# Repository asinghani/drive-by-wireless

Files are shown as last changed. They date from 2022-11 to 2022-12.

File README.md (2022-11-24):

# Distributed Embedded Final Project

UWB drive-by-wireless

## Build Instructions

1. Clone pico-sdk and pico-extras and put them in your environment variables as `PICO_SDK_PATH` and `PICO_EXTRAS_PATH`. Also clone FreeRTOS-Kernel, `smp` branch and put its path as `FREERTOS_KERNEL_PATH`

2. `cd firmware`

3. `rm -r build; mkdir build; cd build` (its safest to delete and re-make the build directory every time because CMake caches things incorrectly sometimes)

4. `cmake .. && make -j8` (this will build all 3 targets - cockpit, steering, and drivetrain)

5. This should yield `zone_cockpit.uf2`, `zone_steering.uf2`, and `zone_drivetrain.uf2` which can be flashed to the boards.

## File Structure

```
- firmware/ (the directory for the firmware)
    - main.c (main entry point, shouldn't put any more code into this file)
    - utils.h (utility functions for math, safety, etc.)
    - config.h (configuration of GPIO pins, etc.)
    - FreeRTOSConfig.h
    - z_cockpit/
        - main_cockpit.c (entry point for cockpit zone)
    - z_drivetrain/
        - main_drivetrain.c (entry point for drivetrain zone)
    - z_steering/
        - main_steering.c (entry point for steering zone)
    - common/ (common stuff)
        - freertos_callbacks.c
    - peripherals/ (drivers for hardware peripherals)
        - testpoints.h (driver for test points)

- experimental/ (for test programs)

- scripts/ (scripts to run on a host machine)
    - proxy_gui.py (the steering wheel proxy, to run on Windows)

- hardware/ (hardware / CAD files)
    - 449pcb_v1/ (PCB CAD)
    - schematic.pdf (board schematic, for easy reference)

```

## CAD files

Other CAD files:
hardware/top_plate.dwg

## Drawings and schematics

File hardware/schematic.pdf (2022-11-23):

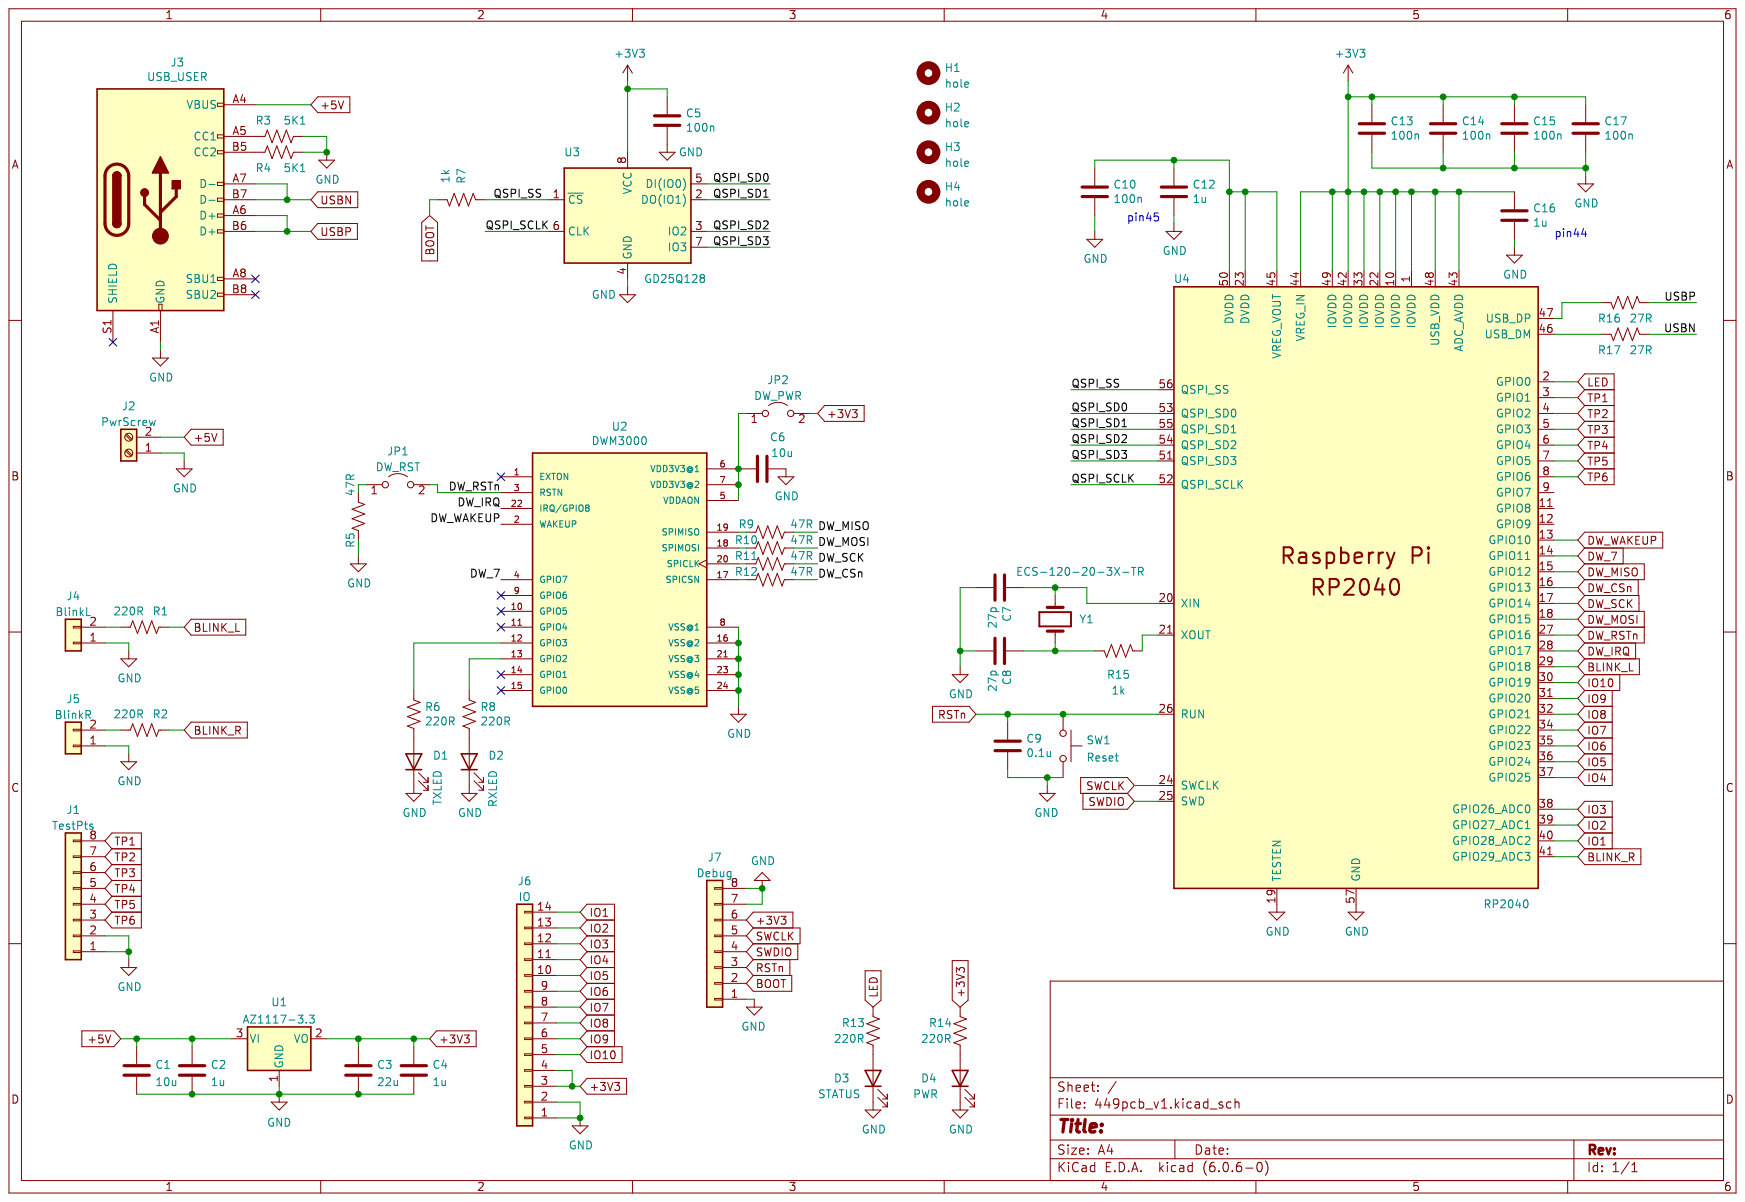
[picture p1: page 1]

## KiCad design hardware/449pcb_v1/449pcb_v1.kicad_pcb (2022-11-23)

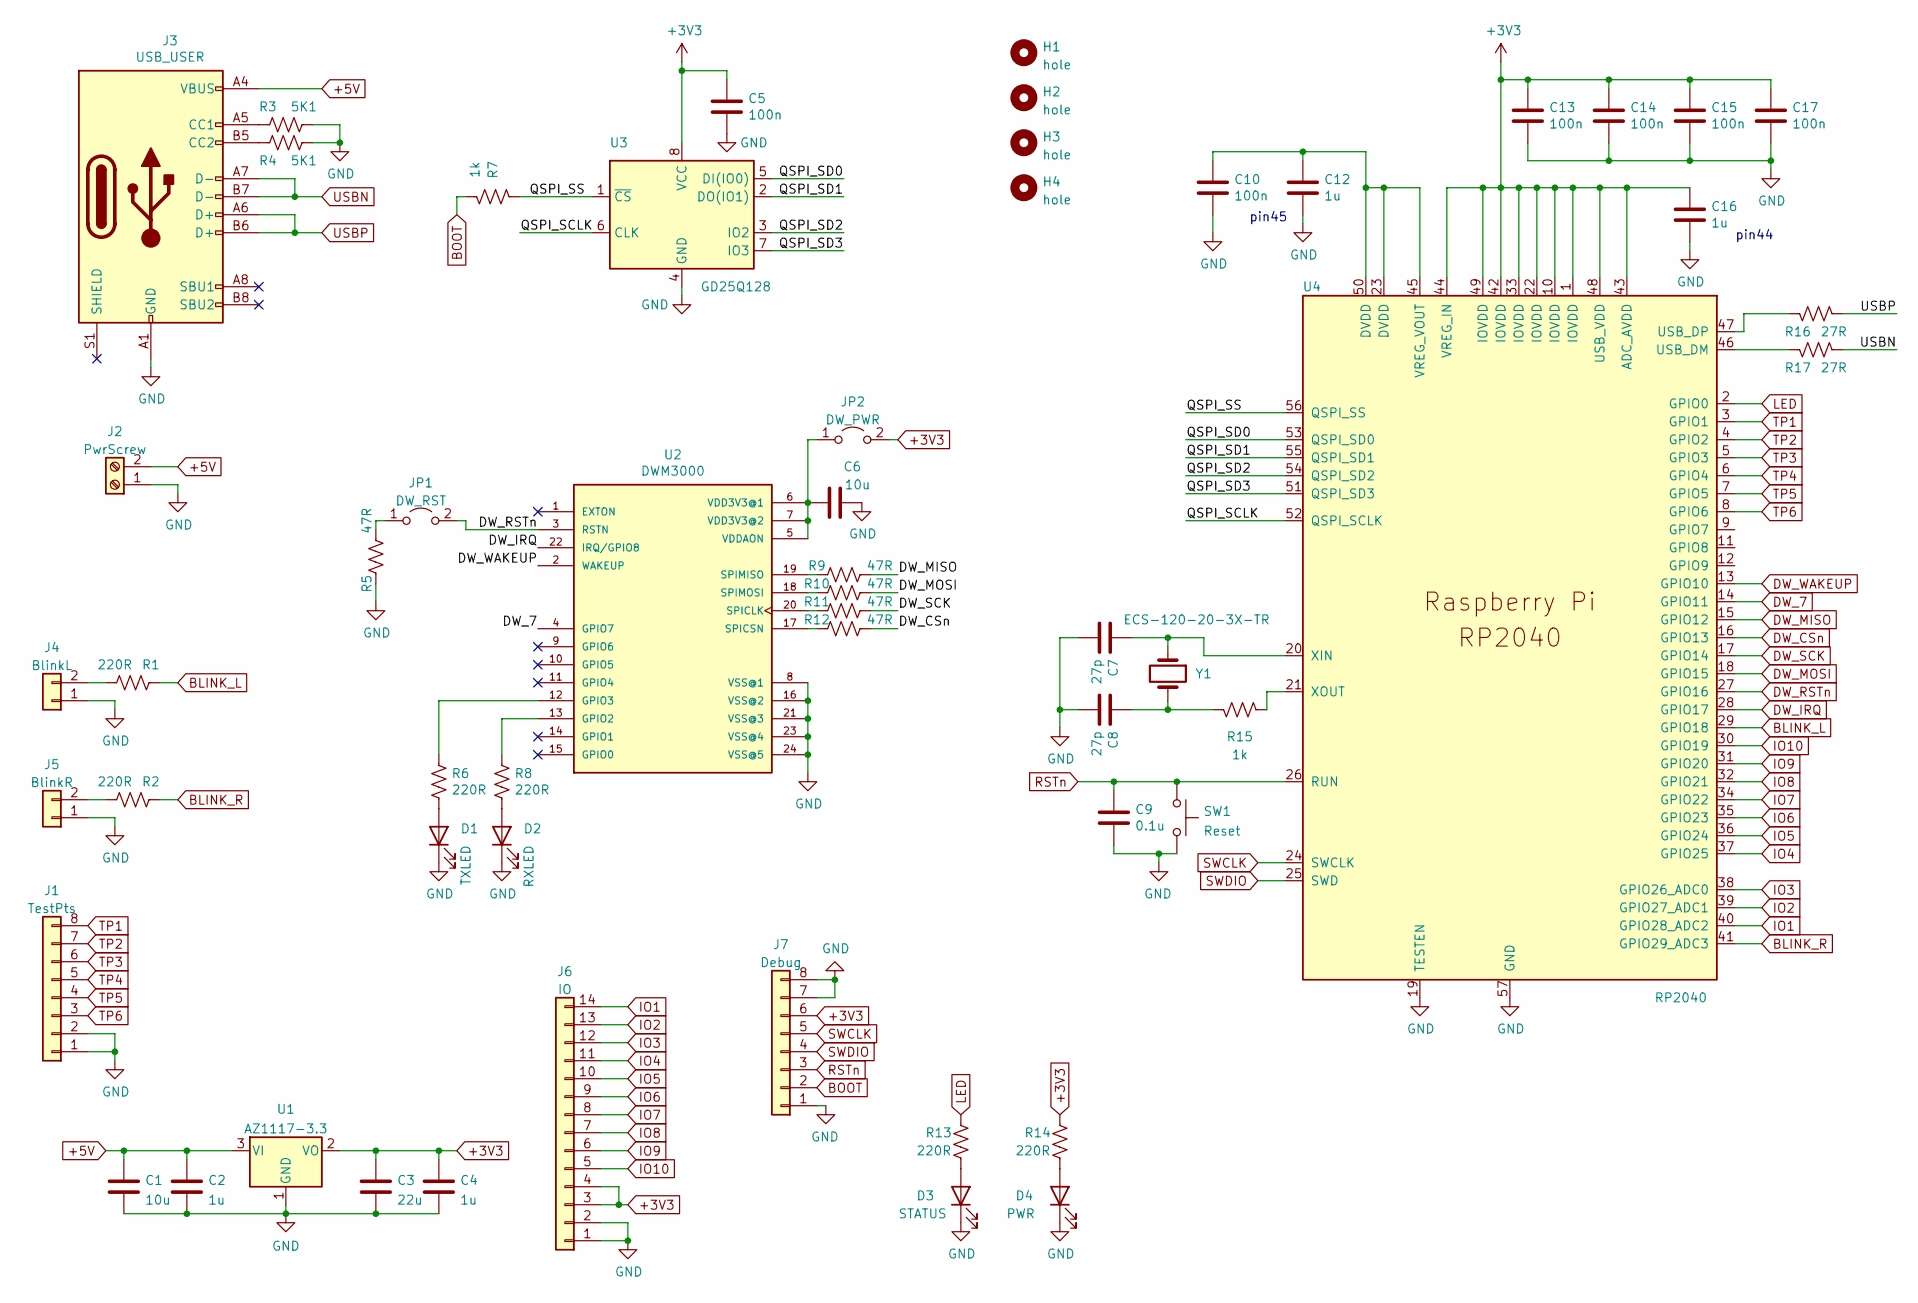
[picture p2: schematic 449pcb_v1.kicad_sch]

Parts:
C1, C6: 10u; C_0603_1608Metric
C2, C4, C12, C16: 1u; C_0603_1608Metric
C3: 22u; C_0603_1608Metric
C5, C10, C13, C14, C15, C17: 100n; C_0603_1608Metric
C7, C8: 27p; C_0603_1608Metric
C9: 0.1u; C_0603_1608Metric
D1: TXLED; LED_0805_2012Metric
D2: RXLED; LED_0805_2012Metric
D3: STATUS; LED_0805_2012Metric
D4: PWR; LED_0805_2012Metric
H1, H2, H3, H4: hole; MountingHole_3.2mm_M3_Pad_Via
J1: TestPts; PinHeader_1x08_P2.54mm_Vertical
J2: PwrScrew; TerminalBlock_4Ucon_1x02_P3.50mm_Horizontal
J3: USB_USER; USB_C_HRO-31-M-12_nofront
J4: BlinkL; PinHeader_1x02_P2.54mm_Vertical
J5: BlinkR; PinHeader_1x02_P2.54mm_Vertical
J6: IO; PinHeader_1x14_P2.54mm_Vertical
J7: Debug; PinHeader_1x08_P2.54mm_Vertical
JP1: DW_RST; PinHeader_1x02_P2.54mm_Vertical
JP2: DW_PWR; PinHeader_1x02_P2.54mm_Vertical
R1, R2, R6, R8, R13, R14: 220R; R_0603_1608Metric
R3, R4: 5K1; R_0603_1608Metric
R5, R9, R10, R11, R12: 47R; R_0603_1608Metric
R7, R15: 1k; R_0603_1608Metric
R16, R17: 27R; R_0603_1608Metric
SW1: Reset; SW_SPST_PTS810
U1: AZ1117-3.3; SOT-223-3_TabPin2
U2: DWM3000
U3: GD25Q128; SOIC-8_5.23x5.23mm_P1.27mm
U4: RP2040; RP2040-QFN-56
Y1: ECS-120-20-3X-TR; XTAL_ECS-120-20-3X-TR

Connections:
+3V3: C3.1, C4.1, C5.1, C13.1, C14.1, C15.1, C16.1, C17.1, J6.3, J6.4, J7.6, JP2.2 (B), R14.1, U1.2 (VO), U3.8 (VCC), U4.1 (IOVDD), U4.10 (IOVDD), U4.22 (IOVDD), U4.33 (IOVDD), U4.42 (IOVDD), U4.43 (ADC_AVDD), U4.44 (VREG_IN), U4.48 (USB_VDD), U4.49 (IOVDD)
+5V: C1.1, C2.1, J2.2, J3.A4 (VBUS), J3.A9 (VBUS), J3.B4 (VBUS), J3.B9 (VBUS), U1.3 (VI)
/QSPI_SCLK: U3.6 (CLK), U4.52 (QSPI_SCLK)
/QSPI_SD0: U3.5 (DI(IO0)), U4.53 (QSPI_SD0)
/QSPI_SD1: U3.2 (DO(IO1)), U4.55 (QSPI_SD1)
/QSPI_SD2: U3.3 (IO2), U4.54 (QSPI_SD2)
/QSPI_SD3: U3.7 (IO3), U4.51 (QSPI_SD3)
/QSPI_SS: R7.2, U3.1 (~CS), U4.56 (QSPI_SS)
BLINK_L: R1.1, U4.29 (GPIO18)
BLINK_R: R2.1, U4.41 (GPIO29_ADC3)
BOOT: J7.2, R7.1
DW_7: U2.4 (GPIO7), U4.14 (GPIO11)
DW_CSn: R12.1, U4.16 (GPIO13)
DW_IRQ: U2.22 (IRQ/GPIO8), U4.28 (GPIO17)
DW_MISO: R9.1, U4.15 (GPIO12)
DW_MOSI: R10.1, U4.18 (GPIO15)
DW_RSTn: JP1.2 (B), U2.3 (RSTN), U4.27 (GPIO16)
DW_SCK: R11.1, U4.17 (GPIO14)
DW_WAKEUP: U2.2 (WAKEUP), U4.13 (GPIO10)
GND: C1.2, C2.2, C3.2, C4.2, C5.2, C6.1, C7.2, C8.2, C9.2, C10.2, C12.2, C13.2, C14.2, C15.2, C16.2, C17.2, D1.1 (K), D2.1 (K), D3.1 (K), D4.1 (K), J1.1, J1.2, J2.1, J3.A1 (GND), J3.A12 (GND), J3.B1 (GND), J3.B12 (GND), J4.1, J5.1, J6.1, J6.2, J7.1, J7.7, J7.8, R3.2, R4.2, R5.2, SW1.2, U1.1 (GND), U2.8 (VSS@1), U2.16 (VSS@2), U2.21 (VSS@3), U2.23 (VSS@4), U2.24 (VSS@5), U3.4 (GND), U4.19 (TESTEN), U4.57 (GND)
IO1: J6.14, U4.40 (GPIO28_ADC2)
IO2: J6.13, U4.39 (GPIO27_ADC1)
IO3: J6.12, U4.38 (GPIO26_ADC0)
IO4: J6.11, U4.37 (GPIO25)
IO5: J6.10, U4.36 (GPIO24)
IO6: J6.9, U4.35 (GPIO23)
IO7: J6.8, U4.34 (GPIO22)
IO8: J6.7, U4.32 (GPIO21)
IO9: J6.6, U4.31 (GPIO20)
IO10: J6.5, U4.30 (GPIO19)
LED: R13.1, U4.2 (GPIO0)
unnamed: C6.2, JP2.1 (A), U2.5 (VDDAON), U2.6 (VDD3V3@1), U2.7 (VDD3V3@2)
unnamed: C7.1, U4.20 (XIN), Y1.1
unnamed: C8.1, R15.2, Y1.2
unnamed: C10.1, C12.1, U4.23 (DVDD), U4.45 (VREG_VOUT), U4.50 (DVDD)
unnamed: D1.2 (A), R6.2
unnamed: D2.2 (A), R8.2
unnamed: J3.A5 (CC1), R3.1
unnamed: J3.B5 (CC2), R4.1
unnamed: J4.2, R1.2
unnamed: J5.2, R2.2
unnamed: JP1.1 (A), R5.1
unnamed: R6.1, U2.12 (GPIO3)
unnamed: R8.1, U2.13 (GPIO2)
unnamed: R9.2, U2.19 (SPIMISO)
unnamed: R10.2, U2.18 (SPIMOSI)
unnamed: R11.2, U2.20 (SPICLK)
unnamed: R12.2, U2.17 (SPICSN)
unnamed: D3.2 (A), R13.2
unnamed: D4.2 (A), R14.2
unnamed: R15.1, U4.21 (XOUT)
unnamed: R17.2, U4.46 (USB_DM)
unnamed: R16.2, U4.47 (USB_DP)
RSTn: C9.1, J7.3, SW1.1, U4.26 (RUN)
SWCLK: J7.5, U4.24 (SWCLK)
SWDIO: J7.4, U4.25 (SWD)
TP1: J1.8, U4.3 (GPIO1)
TP2: J1.7, U4.4 (GPIO2)
TP3: J1.6, U4.5 (GPIO3)
TP4: J1.5, U4.6 (GPIO4)
TP5: J1.4, U4.7 (GPIO5)
TP6: J1.3, U4.8 (GPIO6)
USBN: J3.A7 (D-), J3.B7 (D-), R17.1
USBP: J3.A6 (D+), J3.B6 (D+), R16.1

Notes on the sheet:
pin44
pin45

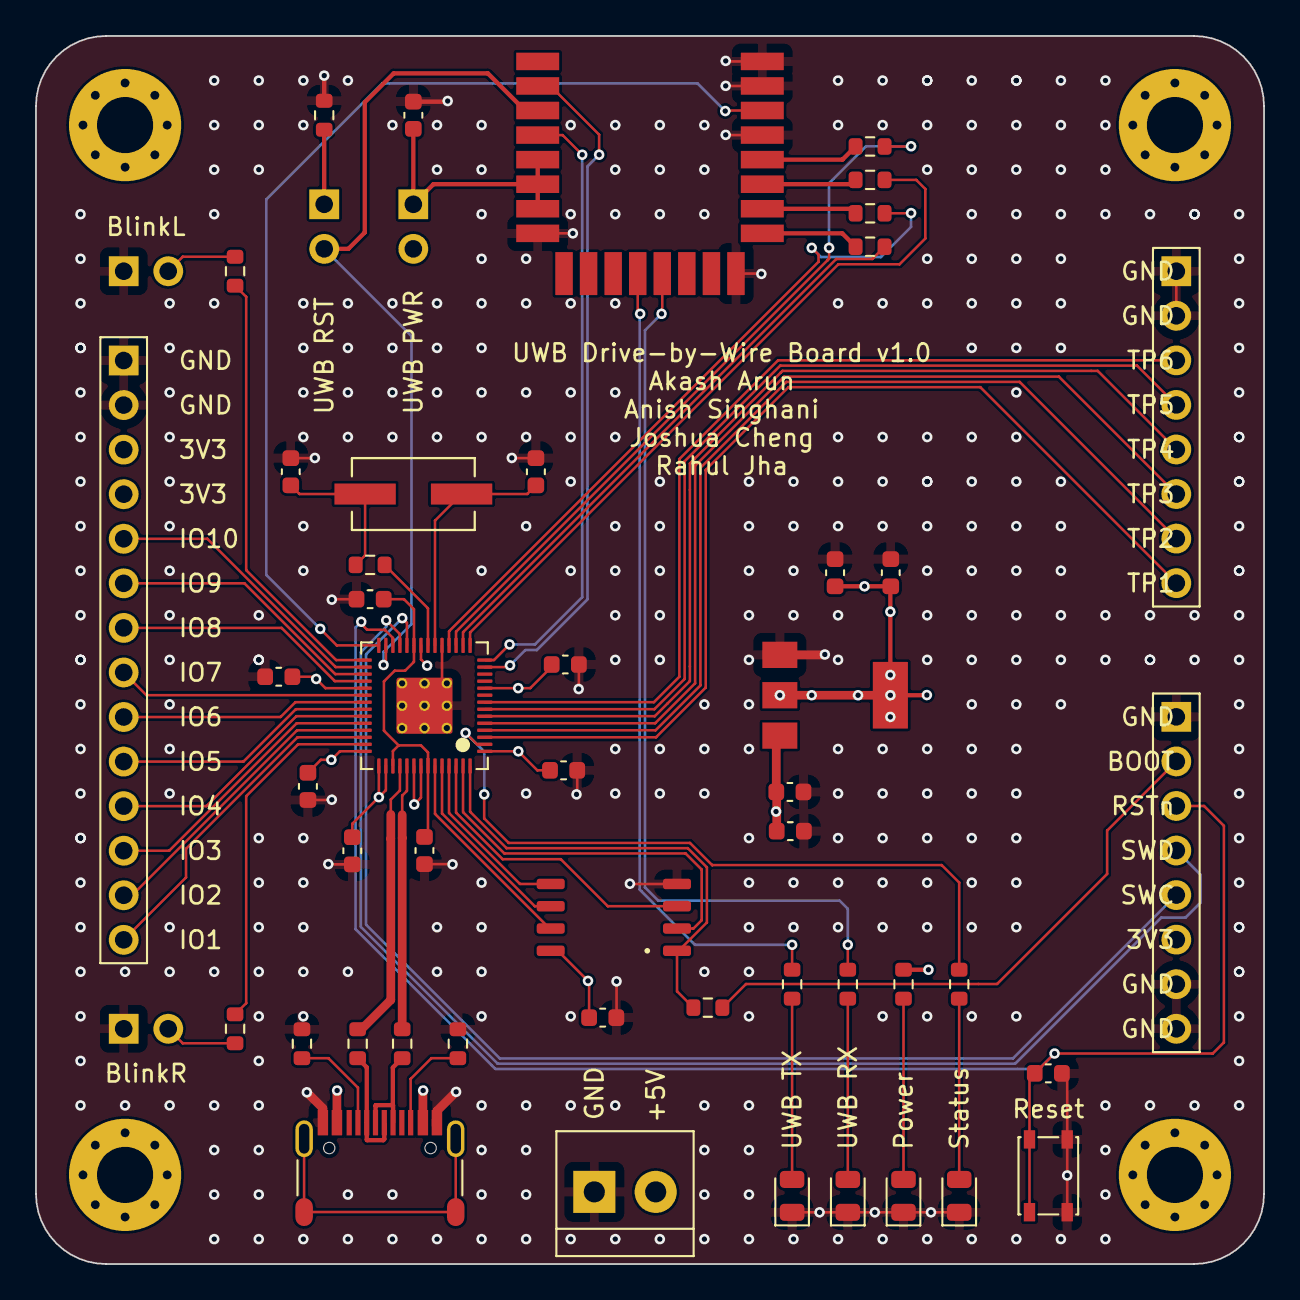
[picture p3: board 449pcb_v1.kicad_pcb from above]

Board: 4 copper layers, 70.0 x 70.0 mm, 56 parts (0 on the bottom side), 64 nets.

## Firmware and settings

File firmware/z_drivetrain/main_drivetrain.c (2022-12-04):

#include "FreeRTOS.h"
#include "task.h"
#include "semphr.h"

#include <stdio.h>
#include <string.h>
#include "peripherals/testpoints.h"
#include "peripherals/blinkers.h"
#include "peripherals/drive_motor.h"
#include "peripherals/voltage_monitor.h"

#include "pico/stdlib.h"
#include "pico/stdio.h"
#include "hardware/adc.h"
#include "hardware/uart.h"
#include "hardware/watchdog.h"
#include "config.h"

#include "crypto/crypto.h"
#include "decawave/uwb_config.h"
#include "decawave/uwb_library.h"
#include "config.h"
#include "utils.h"
#include "types.h"

struct DrivetrainState {
    uint8_t throttle;
    bool brake;
    float voltage_vbat;
    float voltage_vreg;

    // ts_offset = (our clock) - (base clock)
    int32_t ts_offset;
    int32_t blinker_basis_ts;
    bool blink_left;
    bool blink_right;

    bool is_failure_state;
} shm_drivetrain;

// Hardware setup
void drivetrain_setup() {
    memset(&shm_drivetrain, 0, sizeof(shm_drivetrain));

    uwb_init();
    blinkers_init();
    drive_motor_init();
    voltage_monitor_init();

    // Setup LED strip
    uart_init(DRIVETRAIN_LED_STRIP_UART, 115200);
    gpio_set_function(DRIVETRAIN_LED_STRIP_TX, GPIO_FUNC_UART);
}

static void drivetrain_uwb_task(void *arg);
static void drivetrain_motor_task(void *arg);
static void drivetrain_vmon_task(void *arg);
static void drivetrain_led_strip_task(void *arg);

void drivetrain_main() {
    printf("Start drivetrain_main\n");
    drivetrain_setup();

    TaskHandle_t uwb_task;
    xTaskCreate(drivetrain_uwb_task, "drivetrain_uwb_task",
            configMINIMAL_STACK_SIZE, NULL, tskIDLE_PRIORITY + 3, &uwb_task);
    vTaskCoreAffinitySet(uwb_task, 2);

    TaskHandle_t motor_task;
    xTaskCreate(drivetrain_motor_task, "drivetrain_motor_task",
            configMINIMAL_STACK_SIZE, NULL, tskIDLE_PRIORITY + 2, &motor_task);
    vTaskCoreAffinitySet(motor_task, 1);

    TaskHandle_t vmon_task;
    xTaskCreate(drivetrain_vmon_task, "drivetrain_vmon_task",
            configMINIMAL_STACK_SIZE, NULL, tskIDLE_PRIORITY + 4, &vmon_task);
    vTaskCoreAffinitySet(vmon_task, 1);

    TaskHandle_t led_strip_task;
    xTaskCreate(drivetrain_led_strip_task, "drivetrain_led_strip_task",
            configMINIMAL_STACK_SIZE, NULL, tskIDLE_PRIORITY + 5, &led_strip_task);
    vTaskCoreAffinitySet(led_strip_task, 1);

    printf("Starting scheduler\n");
    vTaskStartScheduler();
}

void _drivetrain_uwb_task_idle() {
    blinkers_update(shm_drivetrain.ts_offset, shm_drivetrain.blinker_basis_ts, shm_drivetrain.blink_left,
                        shm_drivetrain.blink_right, shm_drivetrain.is_failure_state);
}

static uint8_t tx_pkt_raw[120];
static uint8_t tx_pkt_enc[120];
static uint8_t rx_pkt_enc[128];
static uint8_t rx_pkt_raw[128];

static void drivetrain_uwb_task(void *arg) {
	TickType_t tick = xTaskGetTickCount();

    int ctr = 0;
    bool success;
    int32_t last_rx_ts = 0;

    // Use fixed-size buffers to facilitate encryption,
    // but alias them to structs to make manipulation easier
    drivetrain_pkt_t *tx_pkt = (void*) &tx_pkt_raw;
    cockpit_pkt_t *rx_pkt = (void*) &rx_pkt_raw;

    while (true) {
        memset(rx_pkt_raw, 0, sizeof(rx_pkt_enc));
        success = (receive_msg(rx_pkt_enc, _drivetrain_uwb_task_idle) != -1);
        success = success && crypto_decrypt(rx_pkt_enc, rx_pkt_raw);
        if (success && (rx_pkt->src == ZID_COCKPIT) && 
                (rx_pkt->dst == ZONE_ID)) {

            tp_raise(ZD_TP_UWB_RX);

            last_rx_ts = millis();
            shm_drivetrain.throttle = rx_pkt->throttle;
            shm_drivetrain.brake = rx_pkt->brake;
            shm_drivetrain.ts_offset = last_rx_ts - rx_pkt->current_ts;
            shm_drivetrain.blinker_basis_ts = rx_pkt->blinker_basis_ts;
            shm_drivetrain.blink_left = rx_pkt->blink_left;
            shm_drivetrain.blink_right = rx_pkt->blink_right;
            shm_drivetrain.is_failure_state = rx_pkt->is_failure_state;

            tx_pkt->src = ZONE_ID;
            tx_pkt->dst = ZID_COCKPIT;
            tx_pkt->voltage_vbat = shm_drivetrain.voltage_vbat;
            tx_pkt->voltage_vreg = shm_drivetrain.voltage_vreg;
            crypto_encrypt(tx_pkt_raw, tx_pkt_enc);
            tp_raise(ZD_TP_UWB_TX);
            send_msg(sizeof(tx_pkt_enc), tx_pkt_enc, 0, _drivetrain_uwb_task_idle);
        }

        if ((millis() - last_rx_ts) > COMM_TIMEOUT_MS) {
            shm_drivetrain.is_failure_state = true;
            shm_drivetrain.throttle = 0;
            shm_drivetrain.brake = true;
        }

        _drivetrain_uwb_task_idle();
        watchdog_update();
        tp_statusled(shm_drivetrain.is_failure_state);
        ctr++;
    }
}

static void drivetrain_motor_task(void *arg) {
	TickType_t tick = xTaskGetTickCount();

    while (true) {
		vTaskDelayUntil(&tick, 5);
        bool is_brake = (shm_drivetrain.is_failure_state ? 1 : shm_drivetrain.brake);
        drive_motor_set(shm_drivetrain.is_failure_state ? 0 : shm_drivetrain.throttle, is_brake);
        tp_raise(ZD_TP_MOTOR_SET);
        tp_set(ZD_TP_IS_BRAKE, is_brake);
    }
}

static void drivetrain_vmon_task(void *arg) {
	TickType_t tick = xTaskGetTickCount();

    while (true) {
		vTaskDelayUntil(&tick, 200);
        shm_drivetrain.voltage_vbat = voltage_monitor_get_vbat();
        shm_drivetrain.voltage_vreg = voltage_monitor_get_5v();
    }
}

static void drivetrain_led_strip_task(void *arg) {
	TickType_t tick = xTaskGetTickCount();

    while (true) {
		vTaskDelayUntil(&tick, 200);
        uint8_t dat = shm_drivetrain.throttle;
        if (shm_drivetrain.is_failure_state) dat = 0;
        if (shm_drivetrain.brake) dat = 0;

        uart_putc_raw(DRIVETRAIN_LED_STRIP_UART, dat);
    }
}

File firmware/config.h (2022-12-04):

#ifndef CONFIG_H
#define CONFIG_H

#define IO_1 28
#define IO_2 27
#define IO_3 26
#define IO_4 25
#define IO_5 24
#define IO_6 23
#define IO_7 22
#define IO_8 21
#define IO_9 20
#define IO_10 19

// Maximum packet loss before failure state
#define MAX_COMM_FAILURES 5
#define COMM_TIMEOUT_MS 80

// Blinker rates
#define ERROR_BLINKER_RATE_MS 150
#define BLINKER_RATE_MS 500

// Blinker control config
#define STEER_THRESH1 30
#define STEER_THRESH2 60

// Cockpit zone config
#define STEERING_UART uart1
#define STEERING_RX IO_8
#define STEERING_TX IO_9

// Steering zone config
#define STEERING_SERVO_IO IO_10
#define STEERING_SERVO_CENTER 1385 // Determined experimentally
#define STEERING_SERVO_RANGE 300
#define STEERING_FEEDBACK_IO IO_1
#define STEERING_FEEDBACK_ADC 2 // ch2 = gpio28

// Drivetrain zone config
#define DRIVETRAIN_EN  IO_8
#define DRIVETRAIN_IN1 IO_9
#define DRIVETRAIN_IN2 IO_10
#define VMON_VBAT IO_1
#define VMON_VBAT_ADC 2 // ch2 = gpio28
#define VMON_5V   IO_2
#define VMON_5V_ADC   1 // ch1 = gpio27

#define DRIVETRAIN_LED_STRIP_UART uart1
#define DRIVETRAIN_LED_STRIP_TX IO_5

// Calibrated emperically
#define VMON_VBAT_SCALE 0.00618871
#define VMON_5V_SCALE 0.00619207

// Blinker I/O pins
#define IO_BLINKL 18
#define IO_BLINKR 29

// UWB I/O pins
#define IO_DW_WAKEUP 10
#define IO_DW_7 11
#define IO_DW_CSn 13
#define IO_DW_RSTn 16
#define IO_DW_IRQ 17

// Test-point I/O pins
#define IO_STATUS 0
#define IO_TP1 1
#define IO_TP2 2
#define IO_TP3 3
#define IO_TP4 4
#define IO_TP5 5
#define IO_TP6 6

// Test point definitions
#define ZC_TP_USB_IN  1
#define ZC_TP_USB_OUT 2
#define ZC_TP_UWB_RX  3
#define ZC_TP_UWB_TX  4

#define ZS_TP_UWB_RX     1
#define ZS_TP_UWB_TX     2
#define ZS_TP_STEER_SET  3
#define ZS_TP_FORCE_READ 4

#define ZD_TP_UWB_RX     1
#define ZD_TP_UWB_TX     2
#define ZD_TP_MOTOR_SET  3
#define ZD_TP_IS_BRAKE   4

#define ZDZS_TP_BLINK_L  5
#define ZDZS_TP_BLINK_R  6

// UWB config
#define UWB_PIN_MISO 12
#define UWB_PIN_CS   13
#define UWB_PIN_SCK  14
#define UWB_PIN_MOSI 15
#define UWB_PIN_RSTN 16
#define UWB_SPI_PORT spi1

// Microseconds to raise test-point for
#define TP_TIME_US 100

#define ZID_COCKPIT 0
#define ZID_STEERING 1
#define ZID_DRIVETRAIN 2

#ifdef ZONE_COCKPIT
#define ZONE_ID ZID_COCKPIT 
#endif

#ifdef ZONE_STEERING
#define ZONE_ID ZID_STEERING
#endif

#ifdef ZONE_DRIVETRAIN
#define ZONE_ID ZID_DRIVETRAIN
#endif

#endif

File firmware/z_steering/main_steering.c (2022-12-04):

#include "FreeRTOS.h"
#include "task.h"
#include "semphr.h"

#include <stdio.h>
#include <string.h>
#include "peripherals/testpoints.h"
#include "peripherals/steering_servo.h"
#include "peripherals/blinkers.h"

#include "pico/stdlib.h"
#include "pico/stdio.h"
#include "hardware/adc.h"
#include "hardware/watchdog.h"
#include "config.h"

#include "crypto/crypto.h"
#include "decawave/uwb_config.h"
#include "decawave/uwb_library.h"
#include "config.h"
#include "utils.h"
#include "types.h"

struct SteeringState {
    int8_t angle;
    int8_t feedback;

    // ts_offset = (our clock) - (base clock)
    int32_t ts_offset;
    int32_t blinker_basis_ts;
    bool blink_left;
    bool blink_right;

    bool is_failure_state;
} shm_steering;

// Hardware setup
void steering_setup() {
    memset(&shm_steering, 0, sizeof(shm_steering));
    steering_servo_init();

    uwb_init();
    blinkers_init();
}

static void steering_uwb_task(void *arg);
static void steering_servo_task(void *arg);
static void steering_feedback_task(void *arg);

void steering_main() {
    printf("Start steering_main\n");
    steering_setup();

    TaskHandle_t uwb_task;
    xTaskCreate(steering_uwb_task, "steering_uwb_task",
            configMINIMAL_STACK_SIZE, NULL, tskIDLE_PRIORITY + 3, &uwb_task);
    vTaskCoreAffinitySet(uwb_task, 2);

    TaskHandle_t servo_task;
    xTaskCreate(steering_servo_task, "steering_servo_task",
            configMINIMAL_STACK_SIZE, NULL, tskIDLE_PRIORITY + 2, &servo_task);
    vTaskCoreAffinitySet(servo_task, 1);

    TaskHandle_t feedback_task;
    xTaskCreate(steering_feedback_task, "steering_feedback_task",
            configMINIMAL_STACK_SIZE, NULL, tskIDLE_PRIORITY + 1, &feedback_task);
    vTaskCoreAffinitySet(feedback_task, 1);

    printf("Starting scheduler\n");
    vTaskStartScheduler();
}

void _steering_uwb_task_idle() {
    blinkers_update(shm_steering.ts_offset, shm_steering.blinker_basis_ts, shm_steering.blink_left,
                        shm_steering.blink_right, shm_steering.is_failure_state);
}

static uint8_t tx_pkt_raw[120];
static uint8_t tx_pkt_enc[120];
static uint8_t rx_pkt_enc[128];
static uint8_t rx_pkt_raw[128];

static void steering_uwb_task(void *arg) {
	TickType_t tick = xTaskGetTickCount();

    int ctr = 0;
    bool success;
    int32_t last_rx_ts = 0;

    // Use fixed-size buffers to facilitate encryption,
    // but alias them to structs to make manipulation easier
    steering_pkt_t *tx_pkt = (void*) &tx_pkt_raw;
    cockpit_pkt_t *rx_pkt = (void*) &rx_pkt_raw;

    while (true) {
        memset(rx_pkt_enc, 0, sizeof(rx_pkt_enc));
        success = (receive_msg(rx_pkt_enc, _steering_uwb_task_idle) != -1);
        success = success && crypto_decrypt(rx_pkt_enc, rx_pkt_raw);
        if (success && (rx_pkt->src == ZID_COCKPIT) && 
                (rx_pkt->dst == ZONE_ID)) {
            tp_raise(ZS_TP_UWB_RX);

            last_rx_ts = millis();
            shm_steering.angle = rx_pkt->angle;
            shm_steering.ts_offset = last_rx_ts - rx_pkt->current_ts;
            shm_steering.blinker_basis_ts = rx_pkt->blinker_basis_ts;
            shm_steering.blink_left = rx_pkt->blink_left;
            shm_steering.blink_right = rx_pkt->blink_right;
            shm_steering.is_failure_state = rx_pkt->is_failure_state;

            tx_pkt->src = ZONE_ID;
            tx_pkt->dst = ZID_COCKPIT;
            tx_pkt->feedback = shm_steering.feedback;

            crypto_encrypt(tx_pkt_raw, tx_pkt_enc);
            tp_raise(ZD_TP_UWB_TX);
            send_msg(sizeof(tx_pkt_enc), tx_pkt_enc, 0, _steering_uwb_task_idle);
        }

        if ((millis() - last_rx_ts) > COMM_TIMEOUT_MS) {
            shm_steering.is_failure_state = true;
            shm_steering.angle = 0;
        }

        _steering_uwb_task_idle();
        watchdog_update();
        tp_statusled(shm_steering.is_failure_state);
        ctr++;
    }
}

static void steering_servo_task(void *arg) {
	TickType_t tick = xTaskGetTickCount();

    while (true) {
		vTaskDelayUntil(&tick, 10);
        steering_servo_set(shm_steering.angle);
        tp_raise(ZS_TP_STEER_SET);
    }
}

static void steering_feedback_task(void *arg) {
	TickType_t tick = xTaskGetTickCount();

    while (true) {
		vTaskDelayUntil(&tick, 10);
        shm_steering.feedback = steering_servo_get_feedback(shm_steering.angle);
        tp_raise(ZS_TP_FORCE_READ);
    }
}

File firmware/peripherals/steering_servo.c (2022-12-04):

#include "FreeRTOS.h"
#include "task.h"
#include "semphr.h"

#include <stdint.h>
#include "pico/stdlib.h"
#include "hardware/adc.h"
#include "hardware/pwm.h"
#include "hardware/clocks.h"

#include "config.h"
#include "utils.h"
#include "steering_servo.h"

float servo_clock_div = 0;
float servo_wrap = 0;

void steering_servo_init() {
    // Set up the servo GPIO and PWM peripheral
    gpio_set_function(STEERING_SERVO_IO, GPIO_FUNC_PWM);
    int slice_num = pwm_gpio_to_slice_num(STEERING_SERVO_IO);
    pwm_config config = pwm_get_default_config();
    uint64_t clock_speed = clock_get_hz(clk_sys);
    servo_clock_div = 64;
    while (clock_speed/servo_clock_div/50 > 65535 && servo_clock_div < 256) servo_clock_div += 64; 
    servo_wrap = clock_speed/servo_clock_div/50;
    pwm_set_gpio_level(STEERING_SERVO_IO, (STEERING_SERVO_CENTER/20000.f)*servo_wrap);
    pwm_config_set_clkdiv(&config, servo_clock_div);
    pwm_config_set_wrap(&config, servo_wrap);
    pwm_init(slice_num, &config, true);
    pwm_set_gpio_level(STEERING_SERVO_IO, (STEERING_SERVO_CENTER/20000.f)*servo_wrap);

    // Set up the current-sensor for feedback
    adc_init();
    adc_gpio_init(STEERING_FEEDBACK_IO);
}

void steering_servo_set(int8_t angle) {
    int x = clamp(angle, -100, 100);
    x = (x * STEERING_SERVO_RANGE) / 100;
    x = x + STEERING_SERVO_CENTER;

    taskENTER_CRITICAL();
    pwm_set_gpio_level(STEERING_SERVO_IO, (x/20000.f)*servo_wrap);
    taskEXIT_CRITICAL();
}

int8_t steering_servo_get_feedback(int8_t cur_angle) {
    taskENTER_CRITICAL();
    adc_select_input(STEERING_FEEDBACK_ADC);
    busy_wait_us(20);
    int adc_out = adc_read();
    taskEXIT_CRITICAL();

    // This calculation was determined emperically to try to get a feedback
    // function that feels somewhat-realistic
    float state = ((cur_angle > 0) ? -1 : 1)*(adc_out-35)*0.3 + (-cur_angle*0.2);
    state = state * 0.5;
    if (absf(cur_angle) < 5) state = 0;
    int8_t out = clamp((int)state, -80, 80);
    return out;
}

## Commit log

2022-11-07 Steering test
2022-11-07 Steering proxy works
2022-11-23 add hardware dir
    [449pcb_v1.kicad_pcb, 449pcb_v1.kicad_sch]
2022-11-24 uart interface
2022-11-24 steering wheel test script updates
2022-11-24 steering threads in cockpit zone
2022-11-24 Pwm motor and servo code
2022-11-25 integrate steering
2022-12-03 drivetrain_motor files
2022-12-03 add car CAD
    [top_plate.dwg]
2022-12-03 add steering emulator script
2022-12-04 add diagnostics thread
2022-12-04 add handling of wheel timeouts
2022-12-04 remove led
2022-12-04 add RGB LEDs
